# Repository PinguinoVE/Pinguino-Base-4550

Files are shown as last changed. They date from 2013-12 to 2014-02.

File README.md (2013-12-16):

Pinguino Base 4550
=====================

Pinguino Base es una alternativa a la placa original del proyecto Pinguino
esta llama Pinguino-tiny4550, siendo '''Pinguino Base''' una mejora substancial
en cuanto a nivel electronico y a nivel de diseño. Siendo su objetivo principal
la capacidad de acoplar ''extensiones'', estas utiles a la hora de realizar
prototipos rapidos de proyectos.

Siendo este diseño muy influenciado en la placa Arduino, pero sin intentar ser
un clon de este, incluso no espera ser compatible pin a pin, con sus shields,
sin embargo se inspira en su arquitectura de hardware para el diseño de los
shields.

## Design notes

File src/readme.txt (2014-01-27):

# Bootloaders:

Un Bootloader (Gestor de arranque) es un pequeño código que se ejecuta una vez que el sistema se inicia. El código se ejecuta dentro del microcontrolador y es responsable de la transferencia de su aplicación desde su PC a la memoria del microcontrolador y entrega el control a esta aplicación después.

Este pequeño codigo, debe ser cargado una unica vez, al momento de construir tu Pinguino, luego de esto, este codigo estara permamentemente dentro de la Memoria RAM del microcontrolador. Para esta carga inicial debes apoyarte en un programdor de PIC tradicional (Siendo esta la unica vez que deberas usar alguno).

# Versiones
Existen 2 versiones del Booloader 100% compatibles con el Diseño de PinguinoBase 4550:

## Versión 2:
Se puede utilizar tanto en 18F2550 y 18F4550.
## Versión 4:
Se escribe con SDCC ( > 3.0.0 ) , con un tamaño alrededor de 3Kb

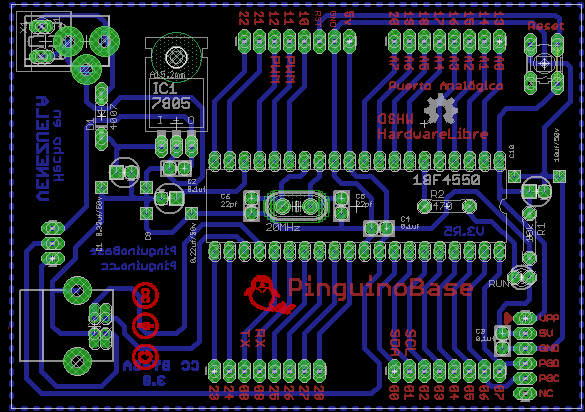
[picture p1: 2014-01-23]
PCB.png

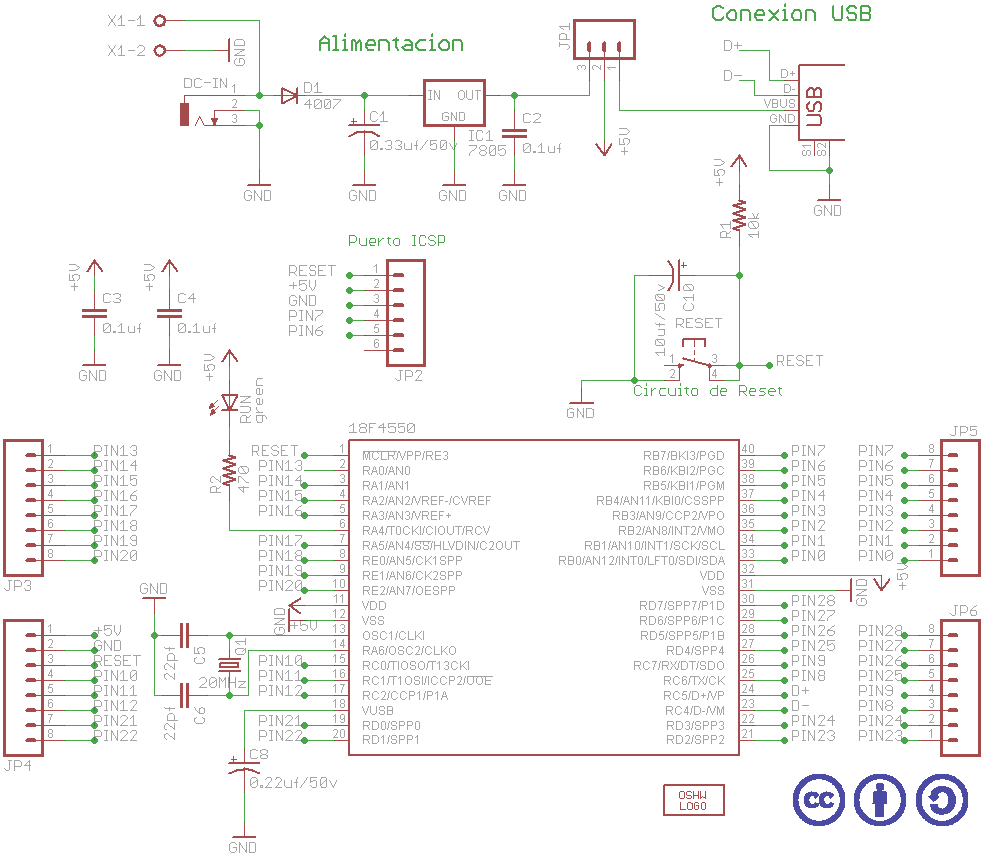
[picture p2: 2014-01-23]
Esquematico.png

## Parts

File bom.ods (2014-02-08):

# de parte del proveedor | Nombre | Descripción | Proveedor | Cantidad | Unidad medida | Precio Unitario | Total
PIC18F4550-I/P-ND | 18F4550 | IC MCU 8BIT 32KB FLASH 40DIP | Digikey | 1 | Unidad | 5,36 USD | 5,36 USD
AE10333-ND | USB | CONN USB 2.0 R/A FMAL TYPE-B PCB | Digikey | 1 | Unidad | 0,88 USD | 0,88 USD
679-2428-ND | RESET | SWITCH TACTILE SPST-NO 0.05A 12V | Digikey | 1 | Unidad | 0,1 | 0,10 USD
 |  |  | Digikey | 1 | Unidad
 |  |  | Digikey
 |  |  | Digikey
 |  |  | Digikey
 |  |  | Digikey
 |  |  | Digikey
 |  |  | Digikey
 |  |  | Digikey
 |  |  | Digikey
 |  |  | Digikey
 |  |  | Digikey
 |  |  | Digikey
 |  |  | Digikey
 |  |  | Digikey
 |  |  | Digikey
 |  |  | Digikey
 |  |  | Digikey
 |  |  | Digikey
 |  |  | Digikey
 |  |  | Digikey
 |  |  | Digikey
 |  |  | Digikey
 |  |  | Digikey
 |  |  | Digikey
 |  |  | Digikey
 |  |  | Digikey
 |  |  | Digikey
 |  |  | Digikey
 |  |  | Digikey

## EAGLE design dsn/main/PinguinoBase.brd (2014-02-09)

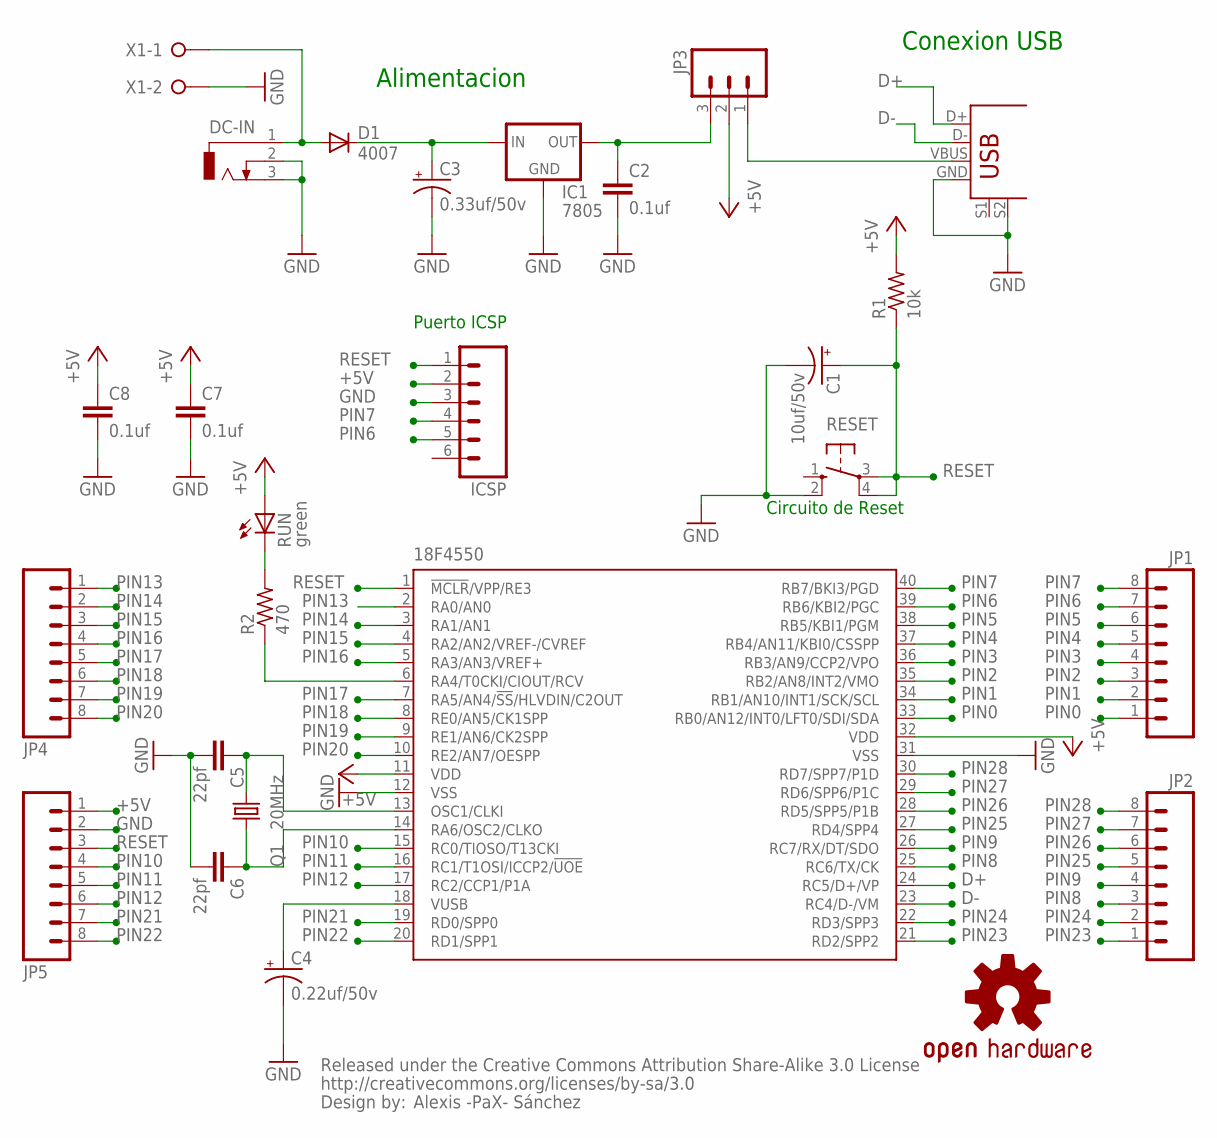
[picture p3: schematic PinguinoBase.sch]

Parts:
18F4550: PIC18F4550_40; DIL40
C1: 10uf/50v; CPOL-RADIAL-10UF-25V
C2, C7, C8: 0.1uf; CAP-PTH-SMALL2
C3: 0.33uf/50v; CPOL-RADIAL-10UF-25V
C4: 0.22uf/50v; CPOL-RADIAL-10UF-25V
C5, C6: 22pf; CAP-PTH-SMALL2
CC_TEXT1: CREATIVE_COMMONS
D1: 4007; DO35-7
DC-IN: DCJ0303
IC1: 7805; 78XXL
ICSP: 1X06_LONGPADS
JP1, JP2, JP4, JP5: 1X08_LONGPADS
JP3: 1X03_LONGPADS
LOGO1: OSHW-LOGOL; OSHW-LOGO-L
Q1: 20MHz; HC49U-V
R1: 10k; 0207/7
R2: 470; 0207/7
RESET: B3F-10XX
RUN: green; LED3MM
USB: USB+SHIELD; USB-B-PTH
X1: W237-132

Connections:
+5V: 18F4550.11 (VDD), 18F4550.32 (VDD), C7.1, C8.1, ICSP.2, JP3.2, JP5.1, R1.2, RUN.A
D+: 18F4550.24 (RC5/D+/VP), USB.D+
D-: 18F4550.23 (RC4/D-/VM), USB.D-
GND: 18F4550.12 (VSS), 18F4550.31 (VSS), C1.2 (-), C2.2, C3.2 (-), C4.2 (-), C5.2, C6.2, C7.2, C8.2, DC-IN.2, DC-IN.3, IC1.GND, ICSP.3, JP5.2, RESET.2 (S1), USB.GND, USB.S2, X1.2
unnamed: 18F4550.13 (OSC1/CLKI), C5.1, Q1.1
unnamed: C3.1 (+), D1.C, IC1.IN
unnamed: C2.1, IC1.OUT, JP3.3
unnamed: JP3.1, USB.VBUS
unnamed: 18F4550.14 (RA6/OSC2/CLKO), C6.1, Q1.2
unnamed: 18F4550.18 (VUSB), C4.1 (+)
unnamed: R2.2, RUN.K (C)
unnamed: 18F4550.6 (RA4/T0CKI/CIOUT/RCV), R2.1
unnamed: D1.A, DC-IN.1, X1.1
PIN0: 18F4550.33 (RB0/AN12/INT0/LFT0/SDI/SDA), JP1.1
PIN1: 18F4550.34 (RB1/AN10/INT1/SCK/SCL), JP1.2
PIN2: 18F4550.35 (RB2/AN8/INT2/VMO), JP1.3
PIN3: 18F4550.36 (RB3/AN9/CCP2/VPO), JP1.4
PIN4: 18F4550.37 (RB4/AN11/KBI0/CSSPP), JP1.5
PIN5: 18F4550.38 (RB5/KBI1/PGM), JP1.6
PIN6: 18F4550.39 (RB6/KBI2/PGC), ICSP.5, JP1.7
PIN7: 18F4550.40 (RB7/BKI3/PGD), ICSP.4, JP1.8
PIN8: 18F4550.25 (RC6/TX/CK), JP2.3
PIN9: 18F4550.26 (RC7/RX/DT/SDO), JP2.4
PIN10: 18F4550.15 (RC0/TIOSO/T13CKI), JP5.4
PIN11: 18F4550.16 (RC1/T1OSI/ICCP2/!UOE), JP5.5
PIN12: 18F4550.17 (RC2/CCP1/P1A), JP5.6
PIN13: 18F4550.2 (RA0/AN0), JP4.1
PIN14: 18F4550.3 (RA1/AN1), JP4.2
PIN15: 18F4550.4 (RA2/AN2/VREF-/CVREF), JP4.3
PIN16: 18F4550.5 (RA3/AN3/VREF+), JP4.4
PIN17: 18F4550.7 (RA5/AN4/!SS!/HLVDIN/C2OUT), JP4.5
PIN18: 18F4550.8 (RE0/AN5/CK1SPP), JP4.6
PIN19: 18F4550.9 (RE1/AN6/CK2SPP), JP4.7
PIN20: 18F4550.10 (RE2/AN7/OESPP), JP4.8
PIN21: 18F4550.19 (RD0/SPP0), JP5.7
PIN22: 18F4550.20 (RD1/SPP1), JP5.8
PIN23: 18F4550.21 (RD2/SPP2), JP2.1
PIN24: 18F4550.22 (RD3/SPP3), JP2.2
PIN25: 18F4550.27 (RD4/SPP4), JP2.5
PIN26: 18F4550.28 (RD5/SPP5/P1B), JP2.6
PIN27: 18F4550.29 (RD6/SPP6/P1C), JP2.7
PIN28: 18F4550.30 (RD7/SPP7/P1D), JP2.8
RESET: 18F4550.1 (!MCLR!/VPP/RE3), C1.1 (+), ICSP.1, JP5.3, R1.1, RESET.3, RESET.4 (P1)

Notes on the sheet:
Alimentacion
Conexion USB
Circuito de Reset
Puerto ICSP
Alexis -PaX- Sánchez

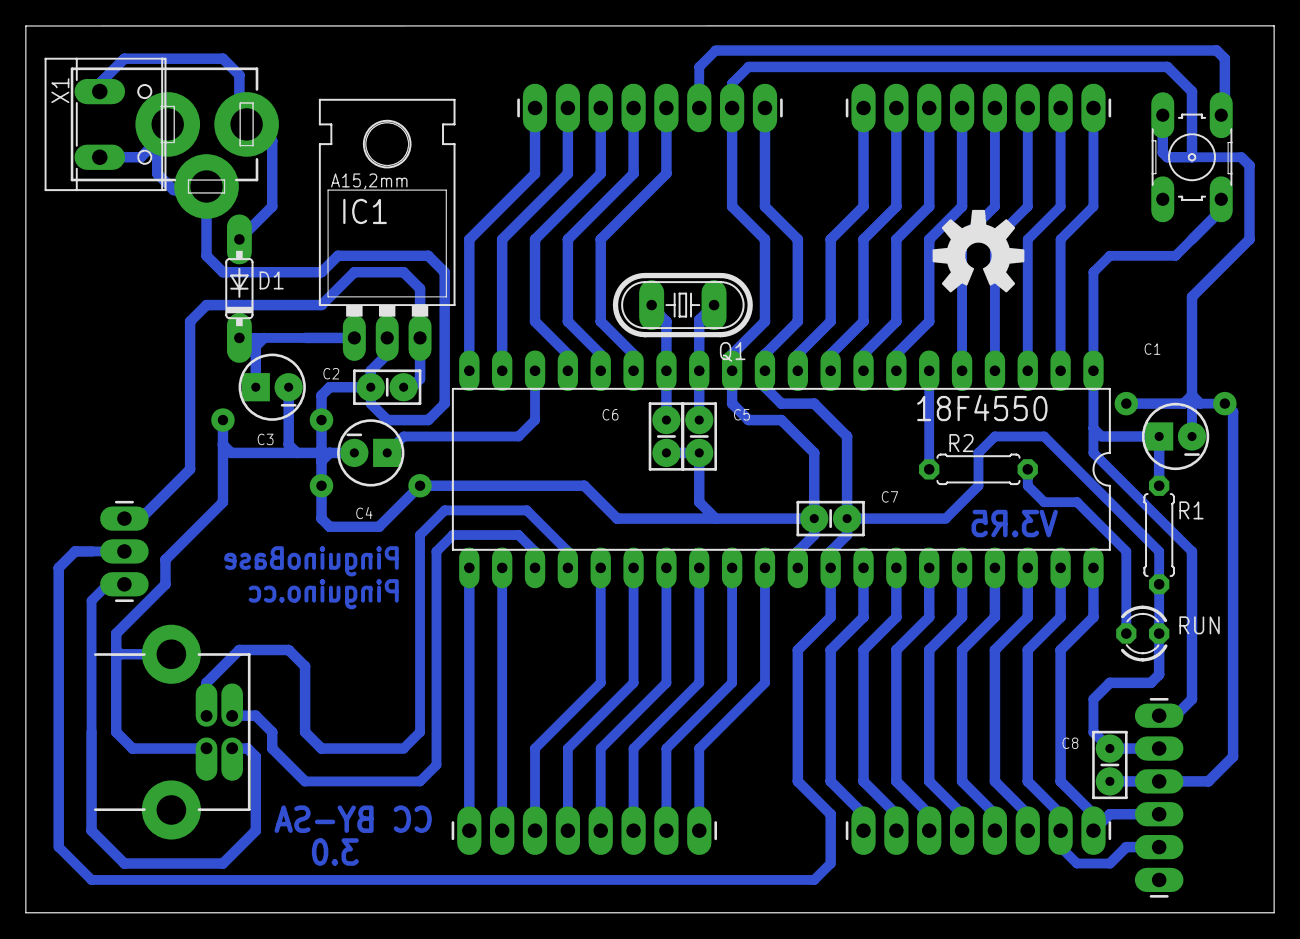
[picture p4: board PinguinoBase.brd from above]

Board: 2 copper layers, 96.5 x 68.6 mm, 27 parts (0 on the bottom side), 43 nets.

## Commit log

2012-03-12 Actualización Eagle 6
    [PBase.brd]
2012-04-30 Update 3v4
    [PinguinoBase.brd, PinguinoBase.sch]
2012-04-30 Clean Up
    [PBase.brd, PBase.sch]
2013-12-16 OpenSource Hardware Good Practice template
    [Test.brd, Test.sch, bom.csv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]
2013-12-16 Diseño
    [PinguinoBase.brd, PinguinoBase.sch, Test.brd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]
2014-01-23 Update R3.5
    Nueva versión de PinguinoBase, a su versión 3.5, algunas modificaciones
    de forma, reorganización de componentes, como el Cristal, capacitores,
    eliminado switch de encendido, reorganizado de pistas.
    [PinguinoBase.brd, PinguinoBase.sch]
2014-01-27 Algunos cambios
    Cambios simples en el diseño
    [PinguinoBase.brd, PinguinoBase.sch, bom.csv]
2014-02-08 some Fixes
    [PinguinoBase.brd, PinguinoBase.sch]
2014-02-08 Renumeracion de Componentes, mejoras en el BOM, y correccion a detalles esteticos en el Board
    [PinguinoBase.brd, PinguinoBase.sch, bom.ods]
2014-02-08 Limpieza de cosas innecesarias
2014-02-09 Modificado posicion del Cristal
    [PinguinoBase.brd]
2015-04-20 Update Licence
    Cambio de licencia de GPL a CC

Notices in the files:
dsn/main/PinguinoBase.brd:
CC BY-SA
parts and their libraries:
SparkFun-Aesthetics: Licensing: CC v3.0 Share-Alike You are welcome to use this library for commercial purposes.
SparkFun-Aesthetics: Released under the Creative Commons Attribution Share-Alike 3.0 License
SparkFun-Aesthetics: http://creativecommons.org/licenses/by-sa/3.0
